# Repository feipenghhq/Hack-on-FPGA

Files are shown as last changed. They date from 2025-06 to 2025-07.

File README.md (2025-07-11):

# Hack-on-FPGA

- [Hack-on-FPGA](#hack-on-fpga)
  - [Overview](#overview)
  - [Motivation](#motivation)
  - [Hack CPU Architecture](#hack-cpu-architecture)
    - [Hack Platform](#hack-platform)
    - [Hack CPU on FPGA](#hack-cpu-on-fpga)
  - [Repository Structure](#repository-structure)
  - [Supported FPGA Boards](#supported-fpga-boards)
  - [Try it on FPGA](#try-it-on-fpga)
    - [Load a Jack Program](#load-a-jack-program)
    - [Programming the FPGA](#programming-the-fpga)

**Hack-on-FPGA** is a collection of implementations of the [Nand2Tetris](https://www.nand2tetris.org/) Hack CPU for various FPGA platforms.

## Overview

The Hack CPU is a 16-bit processor introduced in the Nand2Tetris course. It supports a minimal instruction set and Harvard architecture.

This project reimplements the Hack CPU in Verilog (HDL), adapted for real-world FPGA boards, and extends the system to support VGA and keyboard I/O.

## Motivation

Bring the Hack CPU to life on physical FPGA hardware — for fun, learning, and experimentation.

## Hack CPU Architecture

The Hack CPU design in this repository is based on the [Nand2Tetris Computer Architecture](https://drive.google.com/file/d/1Z_fxYmmRNXTkAzmZ6YMoX9NXZIRVCKiw/view), with modifications to better suit FPGA implementation constraints.

### Hack Platform

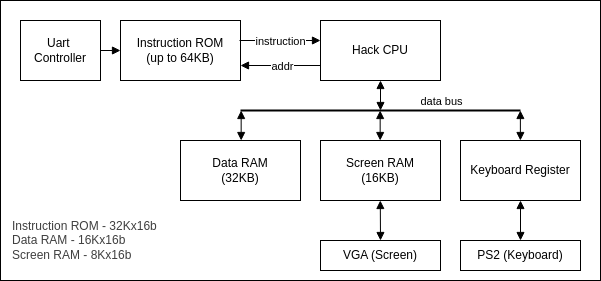
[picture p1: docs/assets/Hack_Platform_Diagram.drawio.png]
Hack_Platform


- Instruction ROM: Store Hack instruction
- Hack CPU: The Hack processor.
- Data RAM: Store the data portion `RAM[0:16383]`
- Screen RAM: Store the data portion `RAM[16384:24575]`
- Uart Controller: Load hack program
- Keyboard Register: Store the current key code at `RAM[24576]`
- VGA Controller: Generates VGA output.
- PS2 keyboard controller: Interfaces with a PS2 keyboard.

### Hack CPU on FPGA

Here is the Hack CPU Design for FPGA:

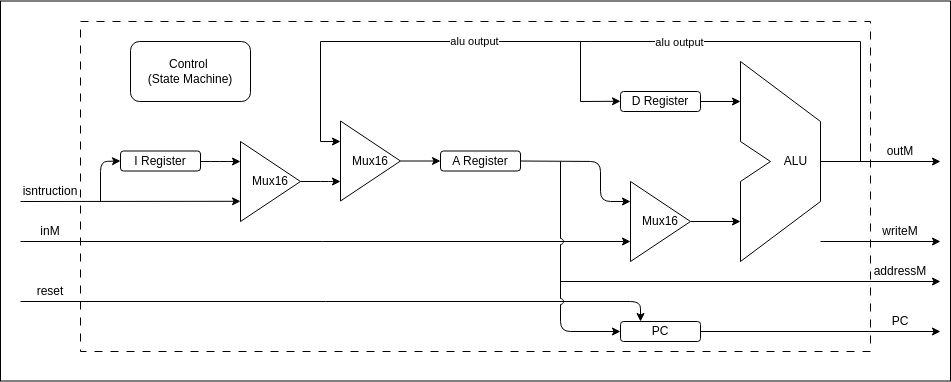
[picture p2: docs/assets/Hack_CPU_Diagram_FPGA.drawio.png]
Hack_CPU


The Hack CPU consist of the following components:
- ALU: Responsible for performing the logic and arithmetic computation.
- A Register, D Register: Standard Hack CPU register.
- PC (Program Counter): Tracks instruction location.
- Control: A Finite State Machine managing CPU states.

Additional components such as the **Control FSM** and **I Register** were added to accommodate synchronous memory in FPGA.

#### Async vs. Sync Memory

In the Nand2Tetris course, ROM and RAM behave as asynchronous memory - data is returned in the same clock cycle.
However, most FPGA RAMs (e.g., BRAM) are synchronous: data is returned in the next clock cycle.

This has two implications:
1. Instruction fetched from ROM becomes available one cycle after the PC is issued.
2. Data read from RAM also returns one cycle later.

#### CPU Control State Machine

To handle sync memory, the CPU uses a three-state FSM (Finite State Machine):

| State | Meaning |
| ----- | --- |
| IDLE  | CPU in reset state |
| FETCH | Fetch the instruction from the ROM |
| EXEC  | Execute the instruction |

- During `FETCH`, the instruction is loaded from ROM.
- `A` register specific the RAM address in `FETCH` state and the RAM data is available in `EXEC` state
- In `EXEC`, the instruction is executed and RAM output becomes valid.
- This approach assumes fixed 1-cycle latency memory. For longer or variable latency, further changes are required.

## Repository Structure

```
Hack-on-FPGA
├── boards              // Board-specific build scripts and constraints
├── docs
├── LICENSE
├── program             // Sample Jack programs + UART load script
├── README.md
├── rtl                 // RTL design file
│   ├── cpu             // Hack CPU Core
│   ├── memory          // RAM/ROM module
│   ├── vga             // VGA
│   ├── uart            // UART
│   └── top             // Top level module
└── software            // Jack/Hack software tool chain
```

## Supported FPGA Boards

| Board | Vendor | Toolchain | Status |
| --- | --- | --- | --- |
| Arty A7 | Xilinx | Vivado | Mostly Supported except for keyboard |
| DE2 | Altera | Quartus | Not Supported - insufficient on-chip RAM |
| DE2-115 | Altera | Quartus | Fully Supported |

## Try it on FPGA

### Load a Jack Program

After program the FPGA, load a `.hack` program using the UART Host script.

- Config the `com_port` in `config.yaml`
- Run the `UartHost.py` script to enter UART Shell:

```shell
cd program
sudo python3 UartHost.py
```

In the UART Shell:

```shell
> program 0 <hack file>
```

**Available Programs:**

- `ScreenTest.hack`: Draw a simple image on screen.
- `Pong.hack`: Classic Pong game (run very fast).

### Programming the FPGA

#### Arty A7

- Requires the Digilent PmodVGA module (connected to JA/JB)

```shell
cd fpga/arty/
make pgmonly
```

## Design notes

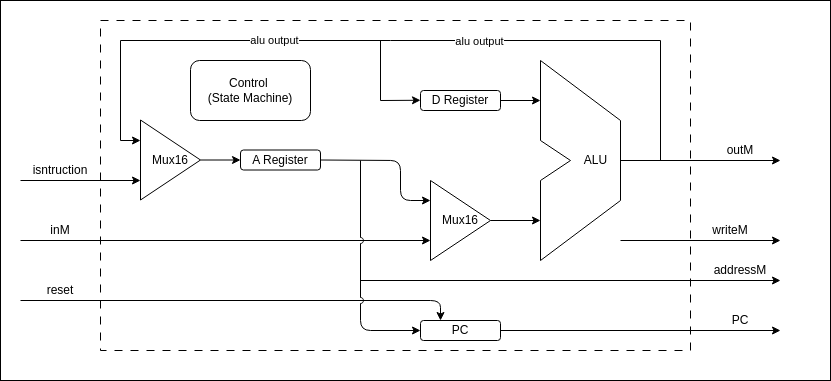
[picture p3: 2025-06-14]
docs/assets/Hack_CPU_Diagram.drawio.png

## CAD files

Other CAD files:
fpga/de2-115/stp1.stp

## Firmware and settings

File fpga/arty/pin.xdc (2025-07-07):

# Clock signal
set_property -dict {IOSTANDARD LVCMOS33  PACKAGE_PIN E3} [get_ports { CLOCK_100 }];

# Reset
set_property -dict {IOSTANDARD LVCMOS33  PACKAGE_PIN C2} [get_ports { RESETn }];

# Uart TX/RX
set_property -dict {IOSTANDARD LVCMOS33  PACKAGE_PIN D10} [get_ports { UART_TXD }];
set_property -dict {IOSTANDARD LVCMOS33  PACKAGE_PIN A9}  [get_ports { UART_RXD }];

## Digilent Pmod VGA XDC for Arty A7-35T
## PMOD VGA is plugged into JA (R/G) and JB (B/Sync)

## VGA Red signals (JA1, JA2, JA3, JA4)
set_property -dict {IOSTANDARD LVCMOS33  PACKAGE_PIN G13} [get_ports {VGA_R[0]}]
set_property -dict {IOSTANDARD LVCMOS33  PACKAGE_PIN B11} [get_ports {VGA_R[1]}]
set_property -dict {IOSTANDARD LVCMOS33  PACKAGE_PIN A11} [get_ports {VGA_R[2]}]
set_property -dict {IOSTANDARD LVCMOS33  PACKAGE_PIN D12} [get_ports {VGA_R[3]}]

## VGA Green signals (JA7, JA8, JA9, JA10)
set_property -dict {IOSTANDARD LVCMOS33  PACKAGE_PIN D13} [get_ports {VGA_G[0]}]
set_property -dict {IOSTANDARD LVCMOS33  PACKAGE_PIN B18} [get_ports {VGA_G[1]}]
set_property -dict {IOSTANDARD LVCMOS33  PACKAGE_PIN A18} [get_ports {VGA_G[2]}]
set_property -dict {IOSTANDARD LVCMOS33  PACKAGE_PIN K16} [get_ports {VGA_G[3]}]

## VGA Blue signals (JB1, JB2, JB3, JB4)
set_property -dict {IOSTANDARD LVCMOS33  PACKAGE_PIN E15} [get_ports {VGA_B[0]}]
set_property -dict {IOSTANDARD LVCMOS33  PACKAGE_PIN E16} [get_ports {VGA_B[1]}]
set_property -dict {IOSTANDARD LVCMOS33  PACKAGE_PIN D15} [get_ports {VGA_B[2]}]
set_property -dict {IOSTANDARD LVCMOS33  PACKAGE_PIN C15} [get_ports {VGA_B[3]}]

## VGA Synchronization signals (JB7, JB8)
set_property -dict {IOSTANDARD LVCMOS33  PACKAGE_PIN J17} [get_ports {VGA_HS}]
set_property -dict {IOSTANDARD LVCMOS33  PACKAGE_PIN J18} [get_ports {VGA_VS}]

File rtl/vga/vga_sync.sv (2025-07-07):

// -------------------------------------------------------------------
// Copyright 2025 by Heqing Huang (feipenghhq@gamil.com)
// -------------------------------------------------------------------
//
// Project: VGA Controller
// Author: Heqing Huang
// Date Created: 06/20/2025
//
// -------------------------------------------------------------------
// vga sync: Generating the vga sync signal (hsync/vsync)
// -------------------------------------------------------------------

`include "vga.svh"

module vga_sync #(
    parameter GEN_PIXEL_ADDR = 1,   // generate pixel address
    parameter GEN_X_ADDR = 1,       // generate X coordinate
    parameter GEN_Y_ADDR = 1        // generate Y coordinate
)(
    input                       clk,        // pixel clock
    input                       rst_n,

    output logic                vga_hsync,  // hsync output
    output logic                vga_vsync,  // vsync output
    output logic                display_on,   // display video

    output logic [`P_SIZE-1:0]  pixel_addr, // pixel address
    output logic [`H_SIZE-1:0]  x_addr,     // pixel x coordinate
    output logic [`V_SIZE-1:0]  y_addr      // pixel y coordinate
);

    // ------------------------------
    // signal Declaration
    // ------------------------------

    logic [`H_SIZE-1:0]   h_count;
    logic [`H_SIZE-1:0]   h_count_next;
    logic [`V_SIZE-1:0]   v_count;
    logic [`V_SIZE-1:0]   v_count_next;

    logic                 h_count_end;
    logic                 v_count_end;

    logic                 h_display;
    logic                 v_display;

    // --------------------------------
    // Logic
    // --------------------------------

    // horizontal and vertical counter end
    assign h_count_end = (h_count == `H_COUNT-1) ? 1'b1 : 1'b0;
    assign v_count_end = (v_count == `V_COUNT-1) ? 1'b1 : 1'b0;

    // horizontal and vertical counter
    always @(*) begin

        if (h_count_end) h_count_next = 'b0;
        else             h_count_next = h_count + 1'b1;

        // vertical counter only update when one line complete
        v_count_next = v_count;
        if (h_count_end) begin
            if (v_count_end) v_count_next = 'b0;
            else             v_count_next = v_count + 1'b1;
        end

    end

    assign h_display = (h_count_next <= `H_DISPLAY-1);
    assign v_display = (v_count_next <= `V_DISPLAY-1);

    always @(posedge clk) begin
        if (!rst_n) begin
            h_count <= '0;
            v_count <= '0;
            vga_hsync <= 1'b0;
            vga_vsync <= 1'b0;
            display_on <= 1'b0;
        end
        else begin
            h_count <= h_count_next;
            v_count <= v_count_next;
            vga_hsync <= (h_count_next < `H_DISPLAY+`H_FRONT_PORCH) |
                         (h_count_next > `H_DISPLAY+`H_FRONT_PORCH+`H_SYNC_PULSE-1);

            vga_vsync <= (v_count_next < `V_DISPLAY+`V_FRONT_PORCH) |
                         (v_count_next > `V_DISPLAY+`V_FRONT_PORCH+`V_SYNC_PULSE-1);
            display_on <= h_display & v_display;
        end
    end


    generate

        // generate pixel addr
        if (GEN_PIXEL_ADDR) begin: gen_pixel_addr
            // use a dedicated counter for pixel_addr to avoid slow * operation
            always @(posedge clk) begin
                if (!rst_n) begin
                    pixel_addr <= 0;
                end
                else begin
                    if (h_display) begin
                        if (pixel_addr == (`PIXELS-1))  pixel_addr <= 0;
                        else pixel_addr <= pixel_addr + 1;
                    end
                end
            end
        end
        else begin: no_pixel_addr
            assign pixel_addr = 0;
        end

        // generate x coordinate
        if (GEN_X_ADDR) begin: gen_x_addr
            assign x_addr = h_display ? h_count : '0;
        end
        else begin: no_x_addr
            assign x_addr = 0;
        end

        // generate y coordinate
        if (GEN_Y_ADDR) begin: gen_y_addr
            assign y_addr = v_display ? v_count : '0;
        end
        else begin: no_y_addr
            assign y_addr = 0;
        end

    endgenerate

endmodule

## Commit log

2025-06-13 Implement the memory and hack_top in hdl
    Uart, VGA, and Keyboard are not included yet
2025-06-23 Add vga to Hack platform and clean lint error
    [vga_sync.sv]
2025-07-03 Replace the instruction rom with SRAM
    - The DE2 FPGA does not have enough on-chip RAM. Add the option to use
    SRAM as instruction ROM.
    - Create sram controller module and update the top level
    - Update the vga_sync module
    [vga_sync.sv]
2025-07-03 Implement the Hack machine to DE2 FPGA board
2025-07-04 Add UartHost to Hack CPU
    The UartHost module is used to program the instruction to the SRAM
2025-07-04 Create testbench to test UartHost and SRAM
2025-07-07 Various update
    - Update the cpu reset to rst_n
    - Update the UartHost and VGA IP to latest version
    - Fix an issue in vga_screen_ctrl. color need to be set to zero when
    display is not turned on
    - Initialize the ram content to 0 for FPGA. This will not work for ASIC
    - Update the RAM size to reflect the correct RAM size
2025-07-07 Implement the Hack machine to Arty-A7 FPGA board
    - Arty fpga related collateral
    - Add the UartHost.py script to load the program to FPGA
    - Update document
2025-07-11 Implement Hack on DE2-115. Fully functional!
    - Create FPGA collateral for DE2-115 Board. Pong is running on this board
    - Update the other FPGA collaterl for newly added keyboard
    [stp1.stp]
